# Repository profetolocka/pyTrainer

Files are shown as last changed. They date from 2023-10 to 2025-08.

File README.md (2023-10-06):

# pyTrainer

**pyTrainer** es un completo kit educativo diseñado para aquellos que desean introducirse en el apasionante mundo del aprendizaje de Micropython.

Ha sido creado teniendo como objetivo la sencillez y la economía, ya que puede ser replicado y construido por estudiantes o aficionados empleando técnicas caseras.

Está formado por una placa principal llamada **pyTrainer BASIC**, módulos de sensores y actuadores para interactuar con el mundo real y piezas impresas en 3D para montar las placas y crear distintas estructuras.

Este conjunto de elementos permite realizar una gran cantidad de experiencias y prácticas para aprender a programar en Micropython de una forma sencilla y divertida.<br>

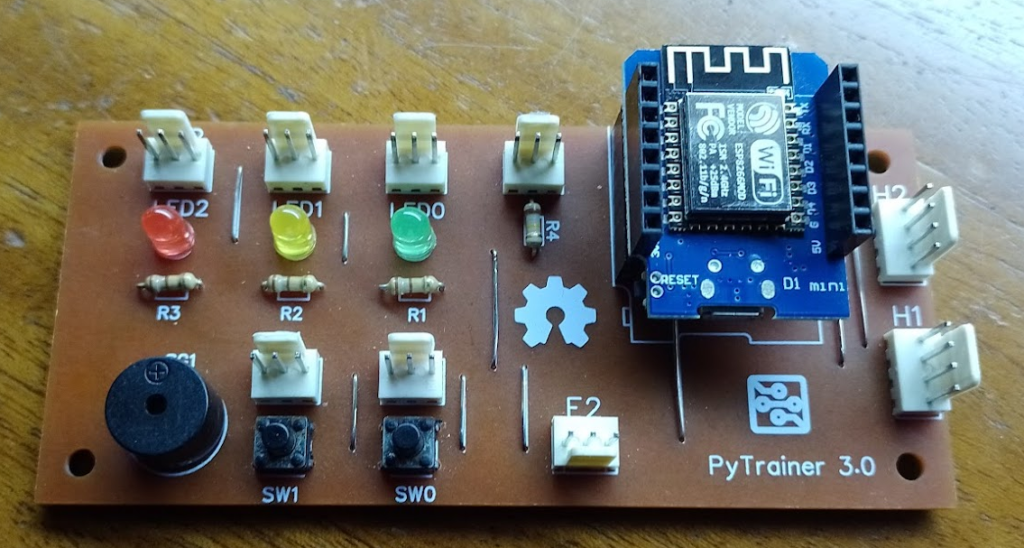
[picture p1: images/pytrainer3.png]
Placa pyTrainer versión 3


## Características

### Sencillez
La placa cuenta con los elementos necesarios para practicar y aprender Micropython sin necesidad de complejas configuraciones. Enchufala y comienza a usarla!

### Potencia
Basada en la D1 Mini de Wemos, cuenta con un módulo ESP8266 capaz de realizar múltiples operaciones y conectarse a Internet a través del Wifi incluido.

### Ampliable
La pyTrainer admite la conexión de distintos módulos que amplian sus capacidades: leds RGB, pulsadores, interruptores, sensores de luz y temperatura, relés son solo algunos de ellos.
Además, el módulo D1 mini acepta distintos shields que se montan sobre la placa, como un display OLED, un sensor de temperatura o una placa de prototipos.

### Hardware y software libre
¿Quieres fabricar tu propia PyTrainer? El diseño es Open Hardware, así que puedes descargar los archivos necesarios para fabricar tu propia placa y modificarla a tu gusto.
 
## Especificaciones
* CPU: Wemos D1 mini
* Salidas digitales: Tres. Cada salida además cuenta con un led testigo.
* Entradas digitales: Tres.
* Pulsadores incorporados: Dos teclas tipo touch de uso múltiple.
* Entradas analógicas: Una con un rango de 0 a 5V.
* Otros: Zumbador activo (Buzzer).
* Ampliación: Dos conectores I2C.

[Toda la información en la Wiki](https://github.com/profetolocka/pyTrainer/wiki)

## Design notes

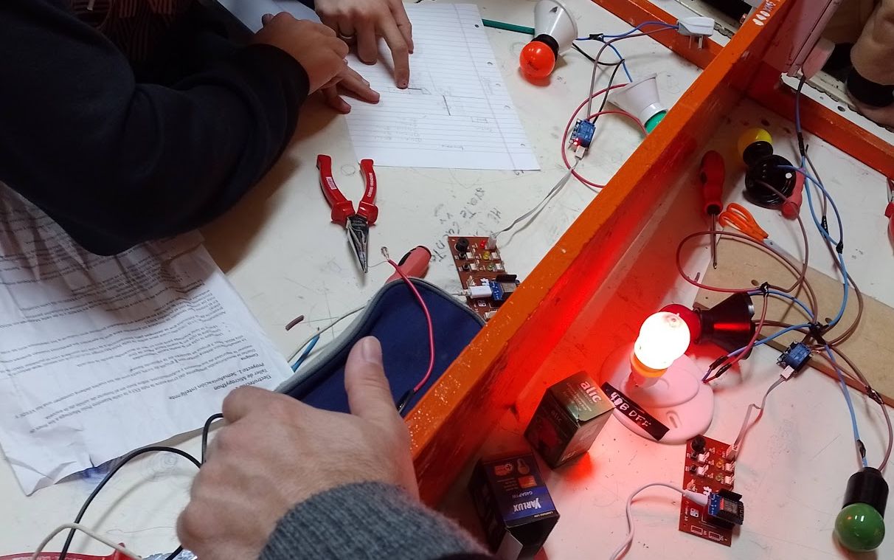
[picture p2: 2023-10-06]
images/pytrainer1.jpg

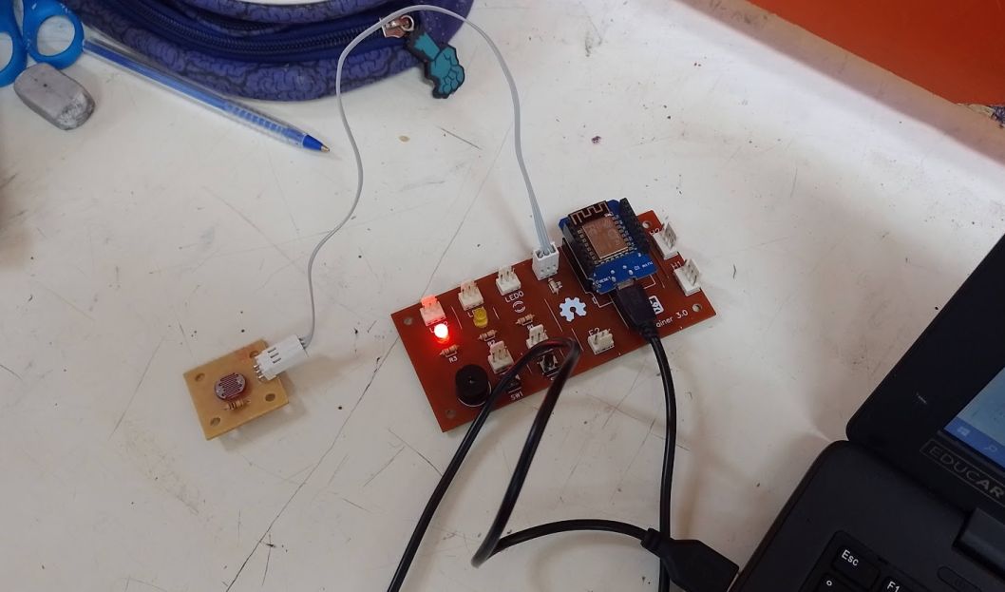
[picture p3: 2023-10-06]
images/pyboard2.jpg

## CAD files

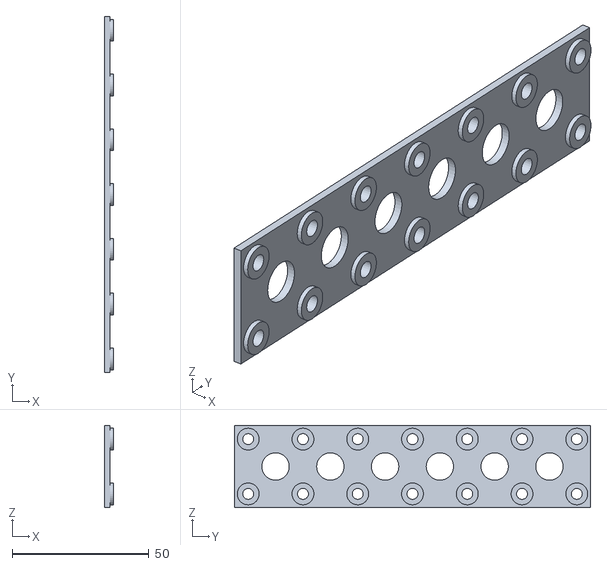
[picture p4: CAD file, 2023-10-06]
parts/R7x2_pupos v4.stl
3.20 x 130.0 x 30.0

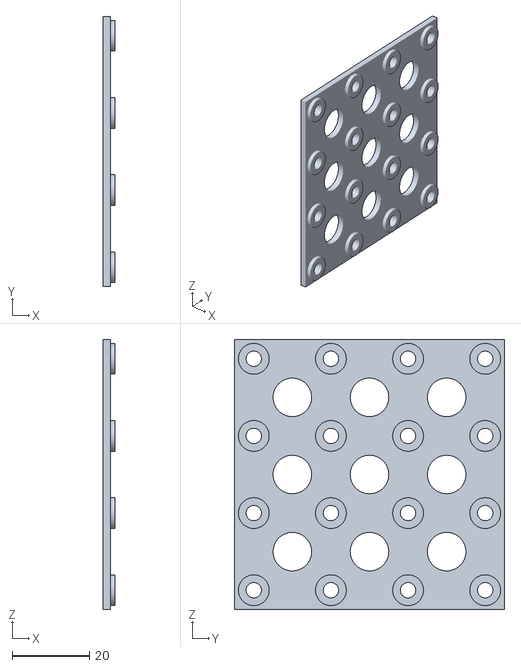
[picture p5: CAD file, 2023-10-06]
parts/C4x4_pupos v2.stl
3.20 x 70.0 x 70.0

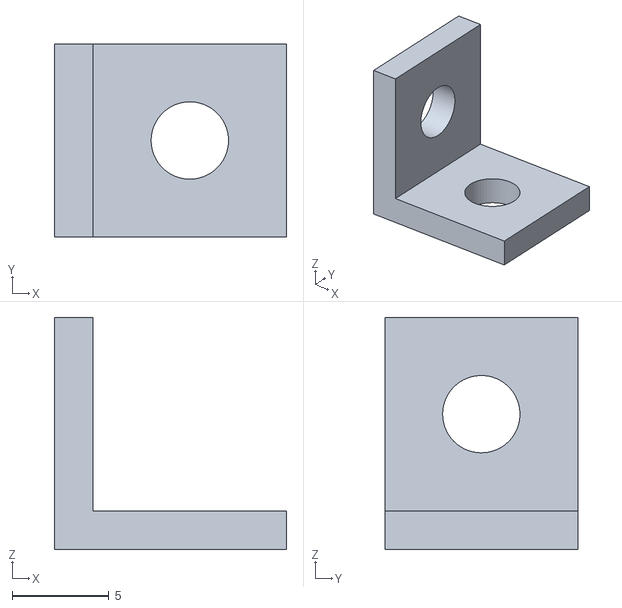
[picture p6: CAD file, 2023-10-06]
parts/Angulo1 v1.stl
12.0 x 10.0 x 12.0

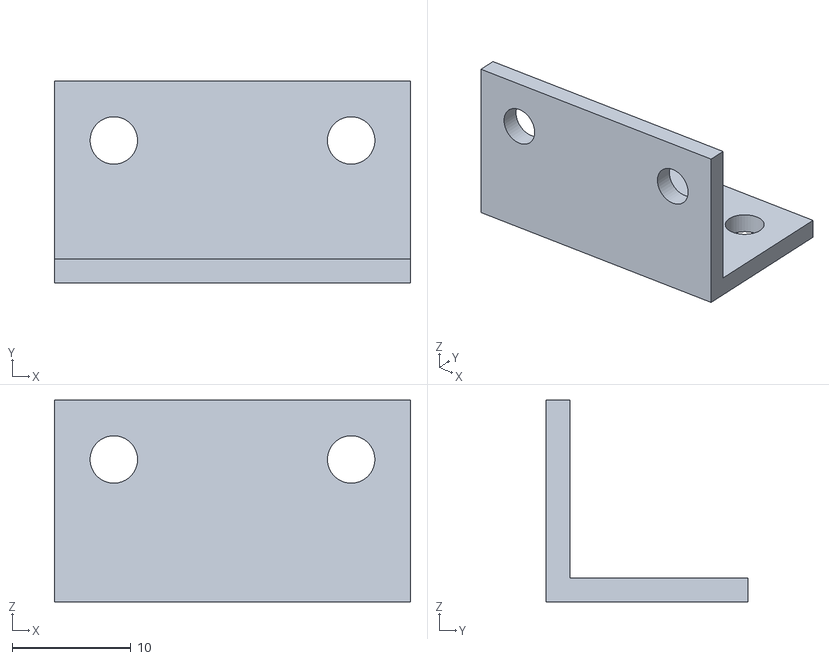
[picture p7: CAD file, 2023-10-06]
parts/Angulo2 v2.stl
30.0 x 17.0 x 17.0

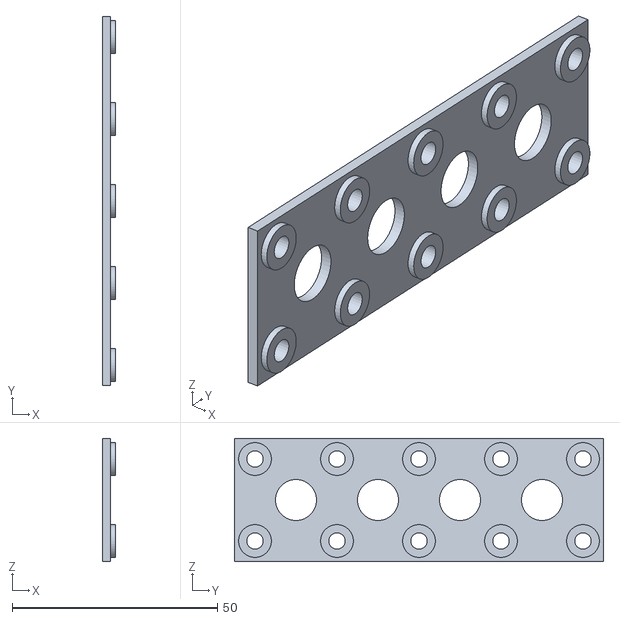
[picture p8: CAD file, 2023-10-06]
parts/R5x2_pupos v1.stl
3.20 x 90.0 x 30.0

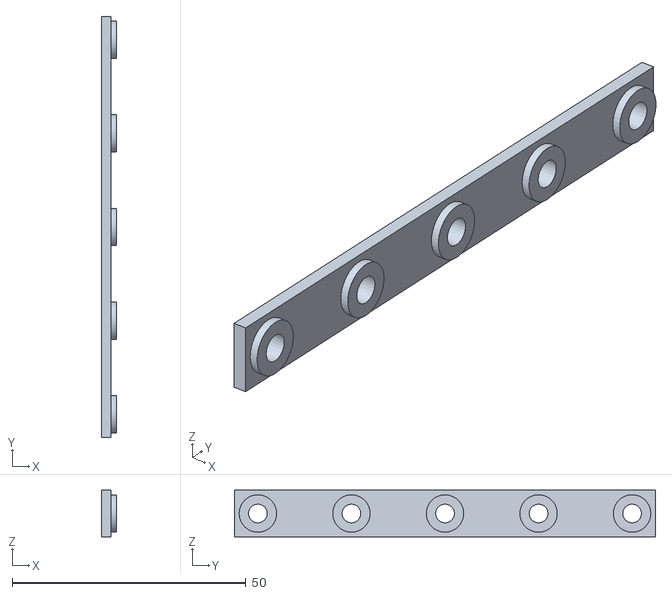
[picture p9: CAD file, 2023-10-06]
parts/R5x1_pupos v2.stl
3.20 x 90.0 x 10.0

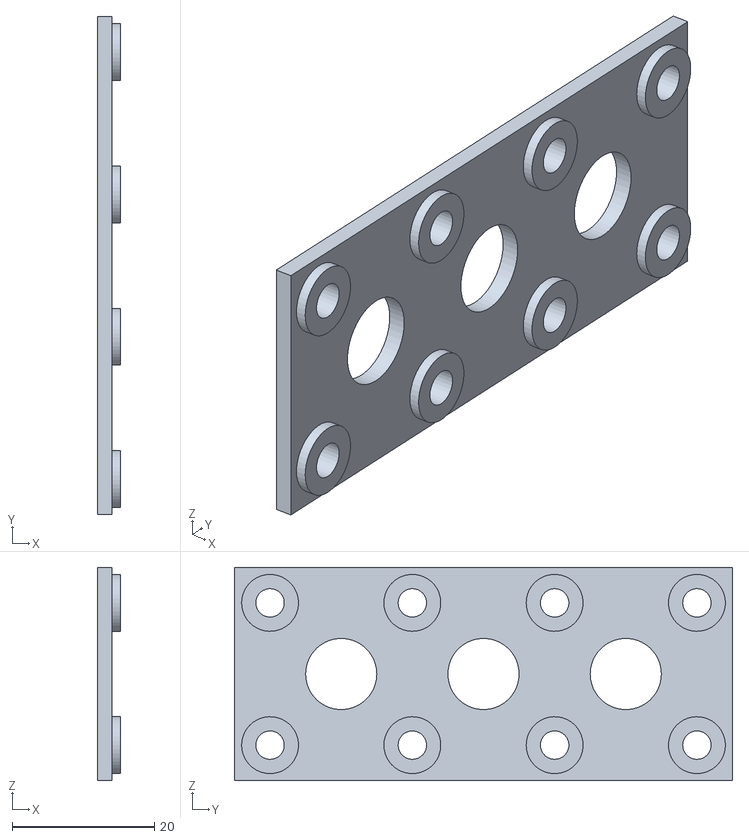
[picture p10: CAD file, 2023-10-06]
parts/R4x2_v4.stl
3.20 x 70.0 x 30.0

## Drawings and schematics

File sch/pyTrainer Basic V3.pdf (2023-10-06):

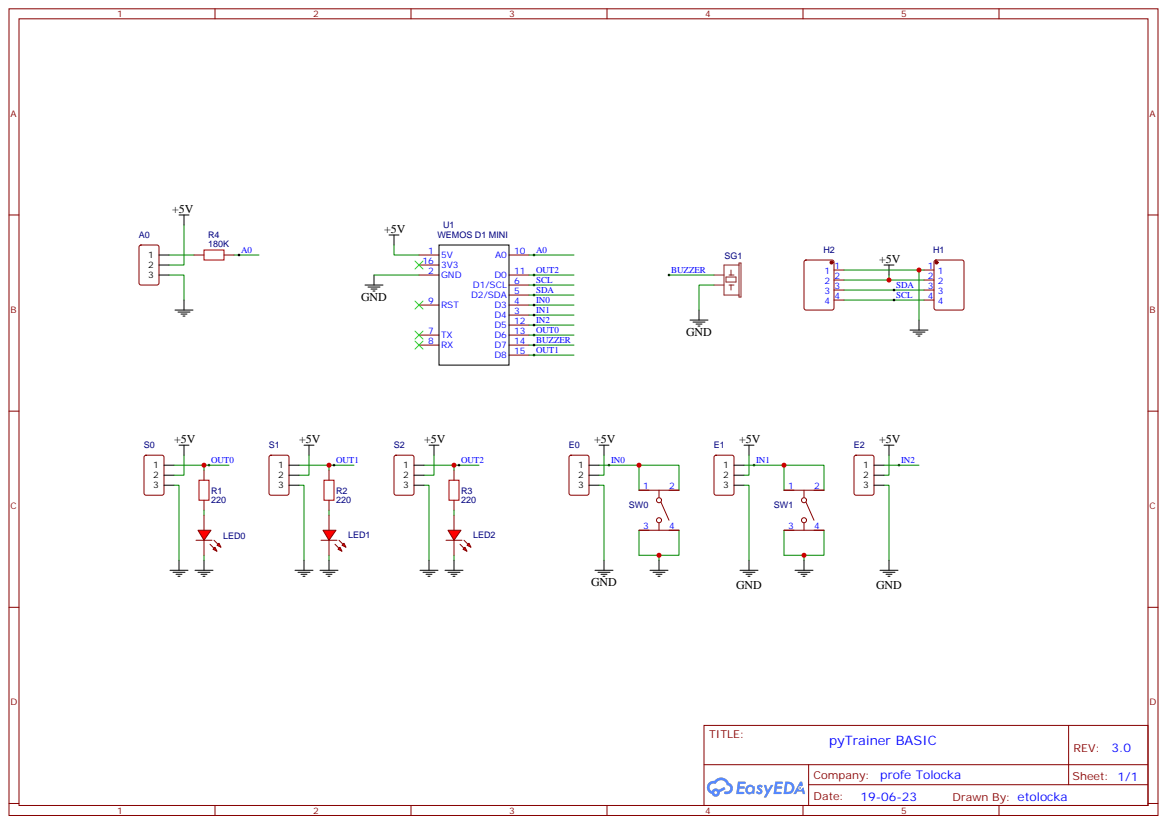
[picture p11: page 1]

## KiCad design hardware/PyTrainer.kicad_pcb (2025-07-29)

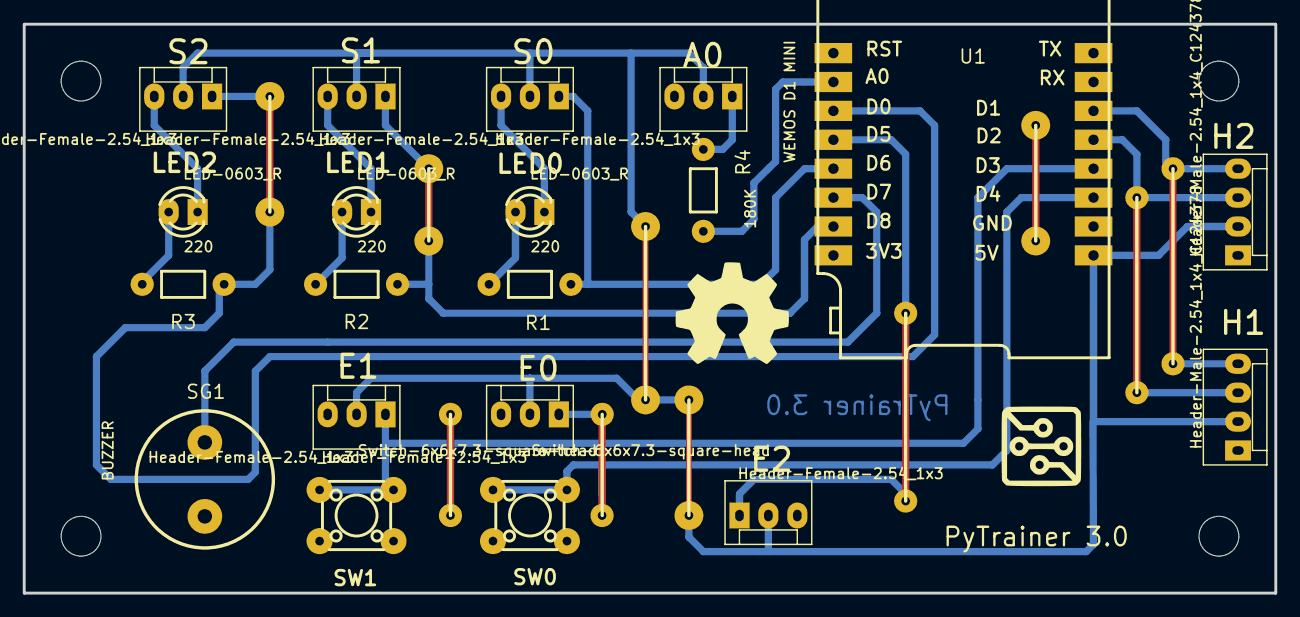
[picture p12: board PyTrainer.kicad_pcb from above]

Board: 2 copper layers, 110.0 x 50.0 mm, 44 parts (0 on the bottom side), 16 nets.

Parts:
A0: Header-Female-2.54_1x3; MOLEX-1X3
E0, E1, E2: Header-Female-2.54_1x3; MOLEX-1X3
H1, H2: Header-Male-2.54_1x4_C124378; MOLEX-1X4
Hole_gge2783: Hole_gge2783
Hole_gge2788: Hole_gge2788
Hole_gge3649: Hole_gge3649
Hole_gge3664: Hole_gge3664
LED0, LED1, LED2: LED-0603_R; LED-TH_BD3.0-P2.54-FD
Pad_gge6454: Pad_gge6454
Pad_gge6466: Pad_gge6466
Pad_gge6478: Pad_gge6478
Pad_gge6490: Pad_gge6490
Pad_gge6502: Pad_gge6502
Pad_gge6514: Pad_gge6514
Pad_gge6526: Pad_gge6526
Pad_gge6538: Pad_gge6538
Pad_gge6550: Pad_gge6550
Pad_gge6562: Pad_gge6562
Pad_gge6574: Pad_gge6574
Pad_gge6586: Pad_gge6586
Pad_gge6598: Pad_gge6598
Pad_gge6610: Pad_gge6610
Pad_gge6622: Pad_gge6622
Pad_gge6634: Pad_gge6634
Pad_gge6655: Pad_gge6655
Pad_gge6667: Pad_gge6667
Pad_gge6679: Pad_gge6679
Pad_gge6691: Pad_gge6691
R1, R2, R3: 220; RD-3.2X1.8-1/8W
R4: 180K; RD-3.2X1.8-1/8W
S0, S1, S2: Header-Female-2.54_1x3; MOLEX-1X3
SG1: BUZZER; BUZZER-12MM-NS
SW0, SW1: Switch-6x6x7.3-square-head; SW-TH_4P-L6.0-W6.0-P4.50-LS6.5
U1: WEMOS D1 MINI

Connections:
+5V: A0.2, E0.2, E1.2, E2.2, H1.2, H2.2, S0.2, S1.2, S2.2, U1.1
A0: R4.2, U1.10
BUZZER: SG1.+, U1.14
GND: A0.3, E0.3, E1.3, E2.3, H1.1, H2.1, LED0.2, LED1.2, LED2.2, S0.3, S1.3, S2.3, SG1.-, SW0.3, SW0.4, SW1.3, SW1.4, U1.2
IN0: E1.1, SW1.1, SW1.2, U1.4
IN1: E0.1, SW0.1, SW0.2, U1.3
IN2: E2.1, U1.12
OUT0: R1.2, S0.1, U1.13
OUT1: R2.2, S1.1, U1.15
OUT2: R3.2, S2.1, U1.11
R1_1: LED0.1, R1.1
R2_1: LED1.1, R2.1
R3_1: LED2.1, R3.1
R4_1: A0.1, R4.1
SCL: H1.4, H2.4, U1.6
SDA: H1.3, H2.3, U1.5

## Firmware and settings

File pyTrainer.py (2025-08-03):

#Definiciones de entradas y salidas de la placa PyTrainer
#Ernesto Tolocka 2023-2025
#www.profetolocka.com.ar/pytrainer

from hcsr04 import HCSR04
import network, time, dht

#Mapeo Dx a GPIOx
D0 = 16       
D1 = 5
D2 = 4
D3 = 0
D4 = 2
D5 = 14
D6 = 12
D7 = 13
D8 = 15


from machine import Pin, ADC, PWM

#Entrada analogica
A0 = ADC (0)

#Medidor de distancias
medidor = HCSR04 (trigger_pin=D2 , echo_pin=D1)

def distancia_cm ():
    return medidor.distance_cm ()

def distancia_mm ():
    return medidor.distance_mm ()


#Leds
ledVerde = Pin (D6, Pin.OUT, value=0)
ledAmarillo = Pin (D8, Pin.OUT, value=0)
ledRojo = Pin (D0, Pin.OUT, value=0)

LED0 = Pin (D6, Pin.OUT, value=0)
LED1 = Pin (D8, Pin.OUT, value=0)
LED2 = Pin (D0, Pin.OUT, value=0)

#Salidas
S0 = Pin (D6, Pin.OUT, value=0)
S1 = Pin (D8, Pin.OUT, value=0)
S2 = Pin (D0, Pin.OUT, value=0)

#Buzzer activo
buzzer = Pin (D7, Pin.OUT, value=0)  

#buzzer pasivo
def bip (duracion):
    zumbador = PWM (Pin(D7), freq=5000, duty=512)
    time.sleep (duracion)
    zumbador.deinit ()

#Teclas
SW0 = Pin (D4, Pin.IN, Pin.PULL_UP)
SW1 = Pin (D3, Pin.IN, Pin.PULL_UP)

#Entradas
E0 = Pin (D4, Pin.IN, Pin.PULL_UP) 
E1 = Pin (D3, Pin.IN, Pin.PULL_UP) 
E2 = Pin (D5, Pin.IN)

#Wifi
def conectaWifi (red, password):
    global miRed
    miRed = network.WLAN(network.STA_IF)     
    if not miRed.isconnected():              #Si no está conectado…
        miRed.active(True)                   #activa la interface
        miRed.connect(red, password)         #Intenta conectar con la red
        print('Conectando a la red', red +"…")
        timeout = time.time ()
        while not miRed.isconnected():           #Mientras no se conecte..
            if (time.ticks_diff (time.time (), timeout) > 10):
                return False
    
    print ("Conexión exitosa!")
    print('Datos de la red (IP/netmask/gw/DNS):', miRed.ifconfig())
      
    return True

## Sensor DHT11
sensorTH = dht.DHT11 (Pin(D5))

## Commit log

2023-10-01 Imagen agregada
    Imagen de la pyTrainer 3 armada
2023-10-06 Se agregan archivos gerber
2023-10-18 Update pyTrainer.py
    Agrega sensor de distancias US
2025-07-29 Agrega hardware
    [PyTrainer.kicad_pcb, PyTrainer.kicad_sch]
2025-07-29 Create boot.py
    Desactiva el wifi por problemas con Mesh
2025-07-29 Update pyTrainer.py
    Agrega bip() para buzzer pasivo
    [pyTrainer.py]
2025-08-03 Update pyTrainer.py
    Incluye DHT11 (pin 5)
